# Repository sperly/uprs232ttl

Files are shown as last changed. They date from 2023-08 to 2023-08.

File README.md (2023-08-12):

# uprs232ttl
TTL Serial Adapter for C64/C128 UserPort.

The adapter is based on a non-inverting cmos buffer chip, CD4050. Following signals are used from the C64/C128:
```
FLAG <- RX (via a jumper)
PB0  <- RX
PB1  -> RTS
PB6  <- CTS
PA2  -> TX
```

There are also jumpers to switch signal path to enable null-modem communication. The default position is marked on pcb and it set for null-modem communication.
```
J4:

 RX/TX
| o o |         Null-Modem
| o o |
  o o

 RX/TX
  o o           Controller-Peripheral
| o o |
| o o |

J5:

CTS/RTS
| o o |         Null-Modem
| o o |
  o o

CTS/RTS
  o o           Controller-Peripheral
| o o |
| o o |

```

The serial output is pin compatible with common serial-usb adapters:
```
1 - GND
2 - CTS
3 - VCC
4 - TX
5 - RX
6 - DTR

```

Jumper 1 is used for enabeling RX interupt on the C64/C128. And jumper 2 is enabeling power thru the serial adapter.
```
J1:

RX Int
| o |         RX interupt enabled
| o |

RX Int
  o           RX interupt disabled
  o 

J2:

 Pwr
| o |         Power feed from C64/C128 enabled
| o |

 Pwr
  o           Power feed from C64/C128 disabled
  o 

```

Top side of pcb:
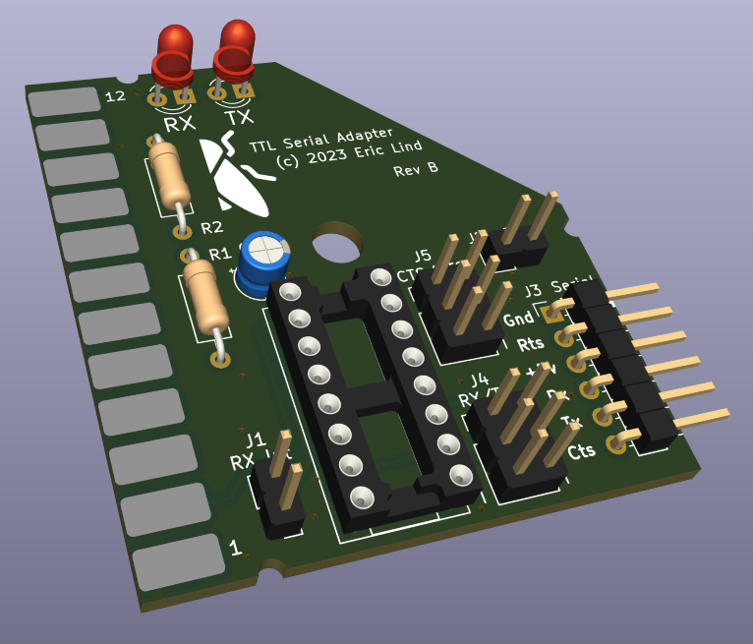
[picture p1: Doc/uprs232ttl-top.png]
Top view of pcb


Bottom side of pcb, also containing info on jumper settings:
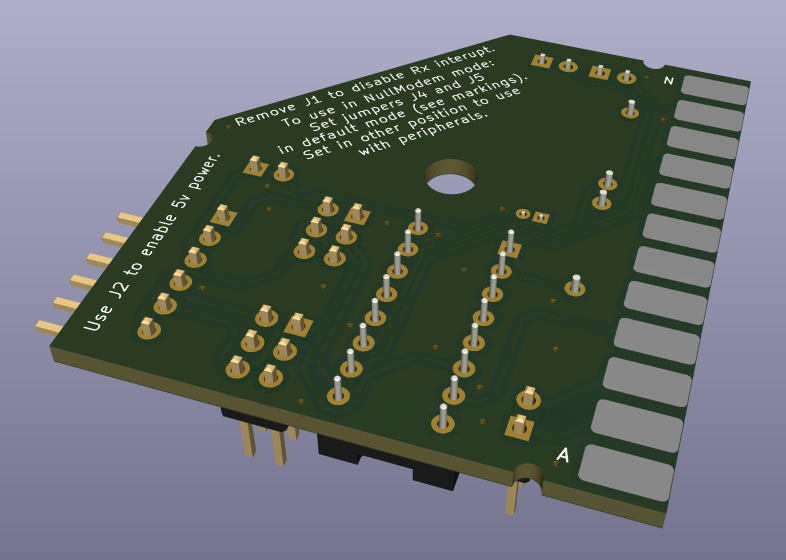
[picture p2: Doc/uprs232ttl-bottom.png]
Bottom view of pcb


Case with pcb:
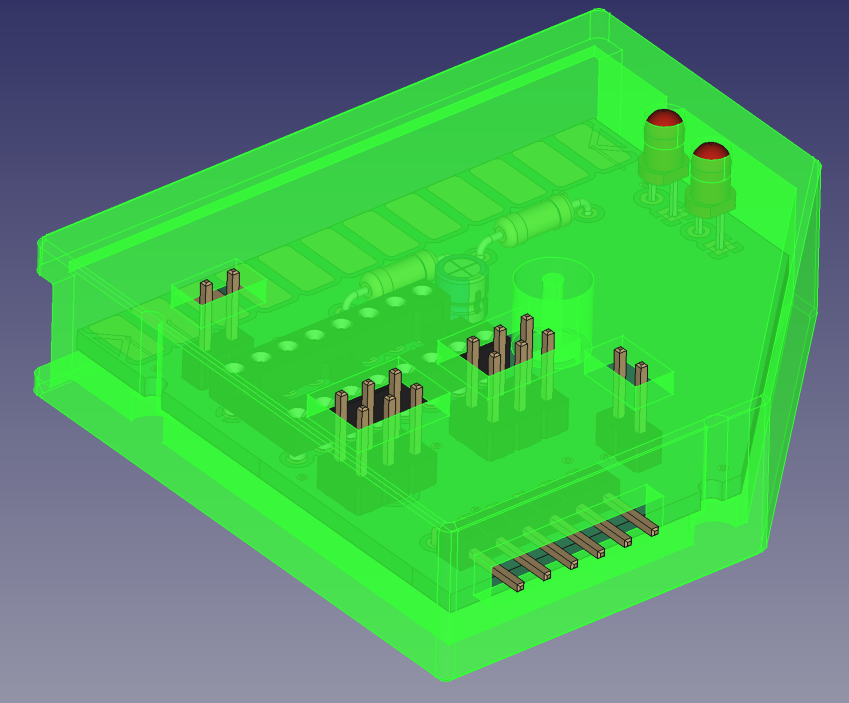
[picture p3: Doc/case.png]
Case with pcb


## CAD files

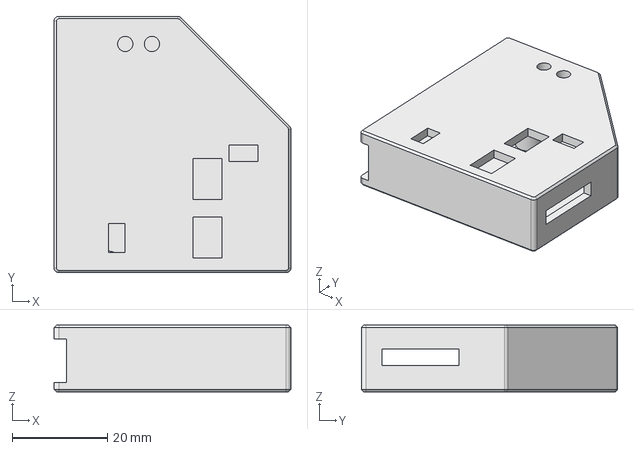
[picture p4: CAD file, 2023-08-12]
Case/uprs232ttl.FCStd
49.7 x 53.8 x 14.0 mm

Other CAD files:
Case/uprs232ttl.stl

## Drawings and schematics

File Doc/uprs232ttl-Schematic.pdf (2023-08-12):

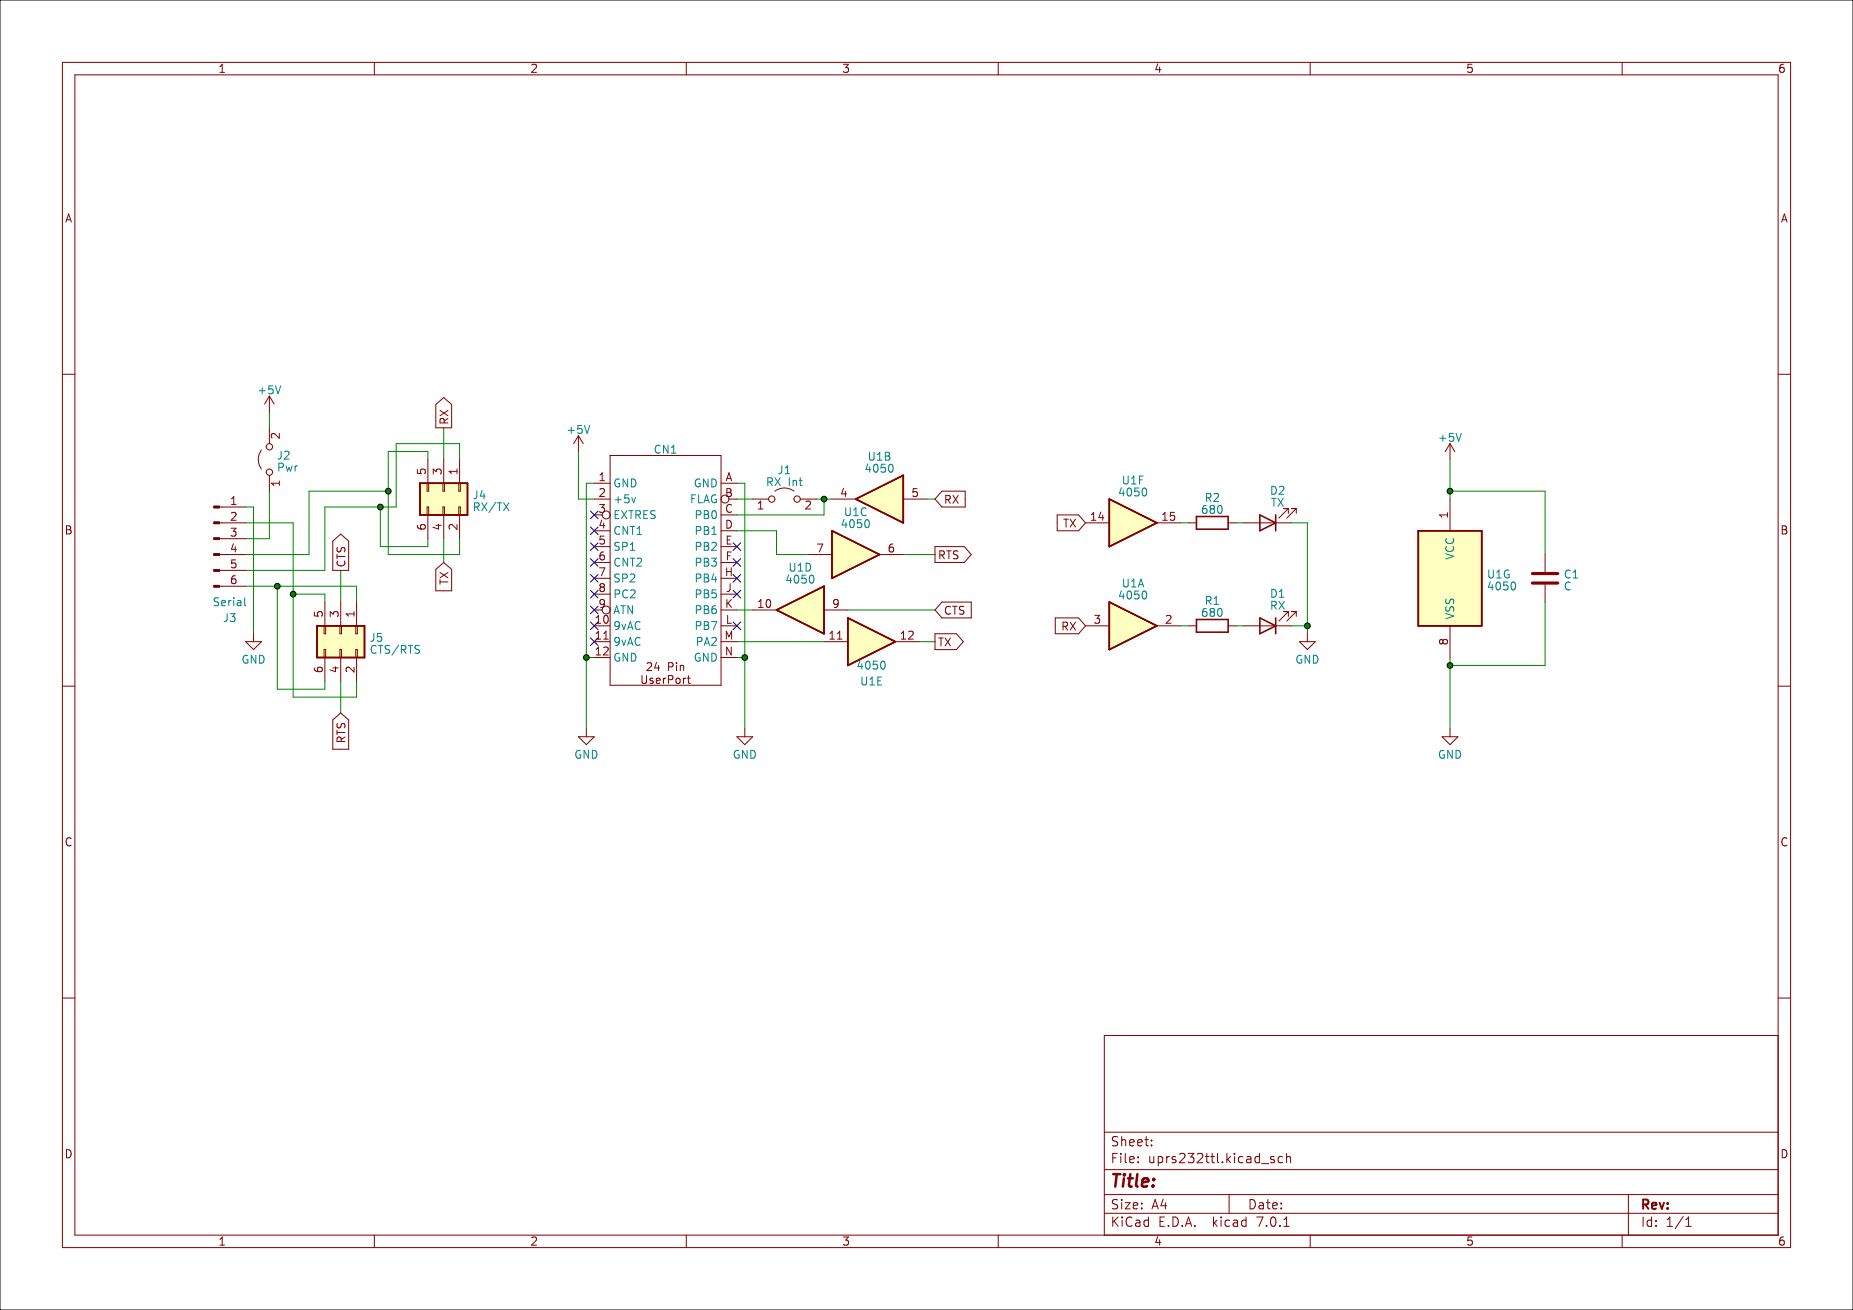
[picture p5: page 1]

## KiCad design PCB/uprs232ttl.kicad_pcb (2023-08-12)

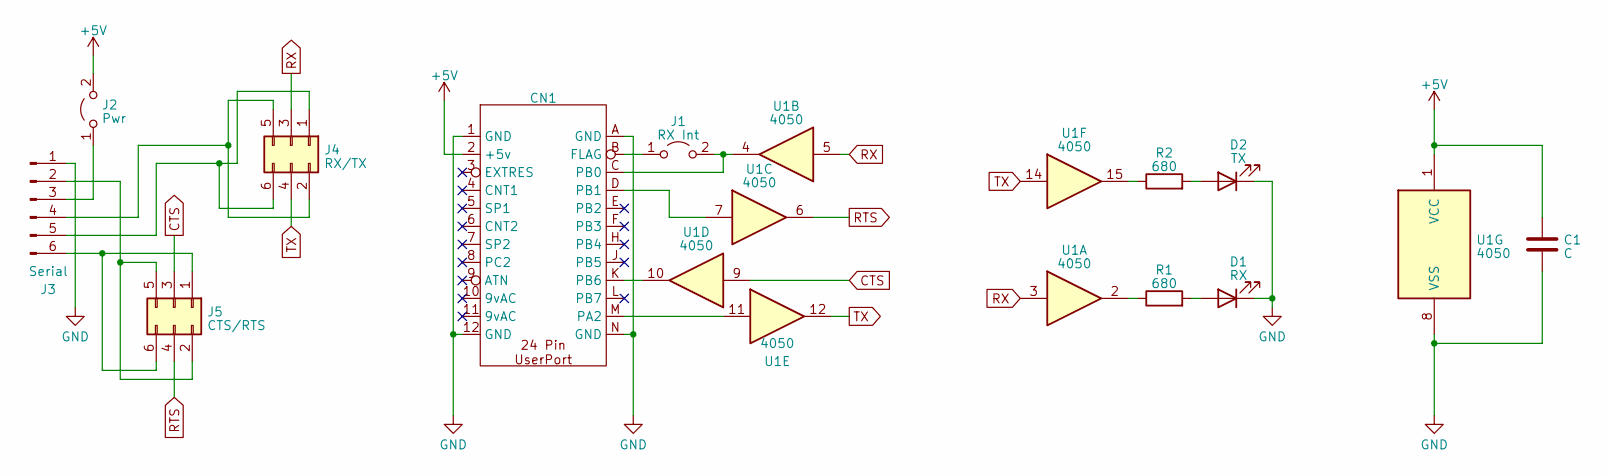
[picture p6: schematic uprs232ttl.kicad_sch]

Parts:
C1: C; CP_Radial_D4.0mm_P1.50mm
CN1: userport_cbm
D1: RX; LED_D3.0mm
D2: TX; LED_D3.0mm
J1: RX Int; PinHeader_1x02_P2.54mm_Vertical
J2: Pwr; PinHeader_1x02_P2.54mm_Vertical
J3: Serial; PinHeader_1x06_P2.54mm_Horizontal
J4: RX/TX; PinHeader_2x03_P2.54mm_Vertical
J5: CTS/RTS; PinHeader_2x03_P2.54mm_Vertical
R1, R2: 680; R_Axial_DIN0207_L6.3mm_D2.5mm_P10.16mm_Horizontal
U1: 4050; DIP-16_W7.62mm_Socket

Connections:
+5V: C1.1, CN1.2 (+5v), J2.2 (B), U1.1 (VCC)
CTS: J5.3, U1.9
GND: C1.2, CN1.1 (GND), CN1.12 (GND), CN1.A (GND), CN1.N (GND), D1.1 (K), D2.1 (K), J3.1, U1.8 (VSS)
unnamed: CN1.B (FLAG), J1.1 (A)
unnamed: CN1.M (PA2), U1.11
unnamed: CN1.C (PB0), J1.2 (B), U1.4
unnamed: CN1.D (PB1), U1.7
unnamed: CN1.K (PB6), U1.10
unnamed: D1.2 (A), R1.2
unnamed: D2.2 (A), R2.2
unnamed: J2.1 (A), J3.3
unnamed: J3.2, J5.2, J5.5
unnamed: J3.4, J4.2, J4.5
unnamed: J3.5, J4.1, J4.6
unnamed: J3.6, J5.1, J5.6
unnamed: R1.1, U1.2
unnamed: R2.1, U1.15
RTS: J5.4, U1.6
RX: J4.3, U1.3, U1.5
TX: J4.4, U1.12, U1.14

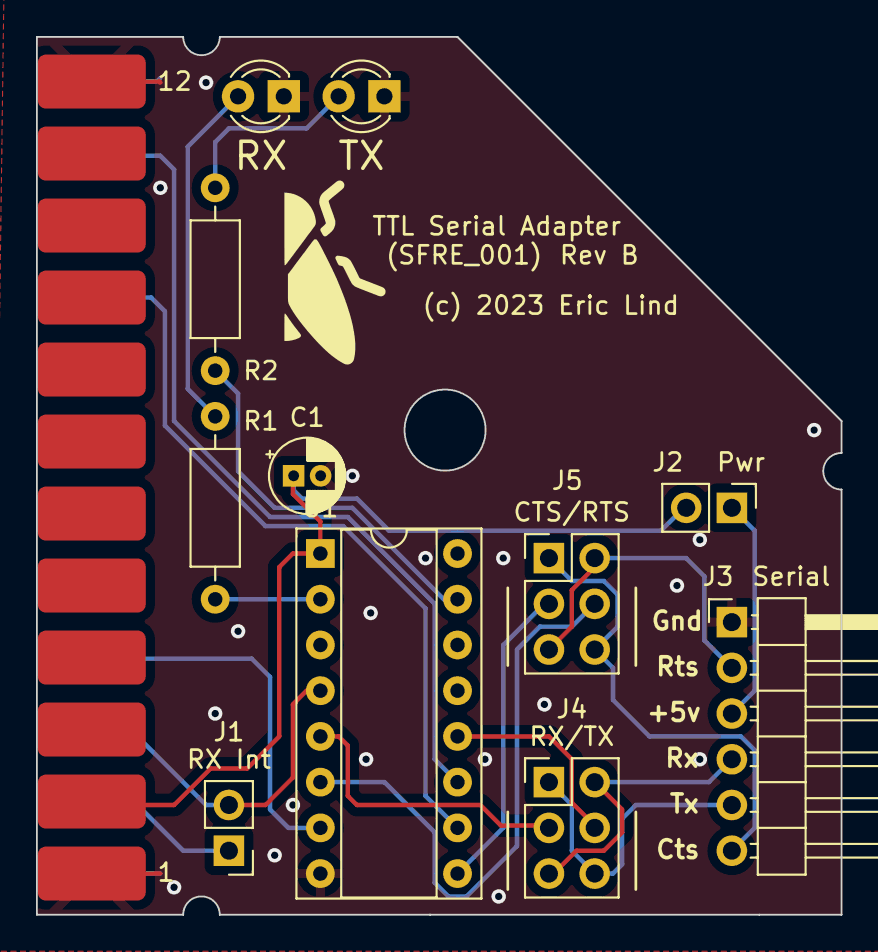
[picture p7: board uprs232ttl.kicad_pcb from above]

Board: 2 copper layers, 44.7 x 48.8 mm, 12 parts (0 on the bottom side), 20 nets.

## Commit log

2023-08-12 Added case, pcb and userport component
    [uprs232ttl-B_Cu.gbr, uprs232ttl-B_Mask.gbr, uprs232ttl-B_Paste.gbr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]
2023-08-12 Added a bottom view of pcb.
2023-08-12 Added a case image and more description in README
2023-08-12 Create .gitignore for pcb folder
2023-08-12 Updated board name
    [uprs232ttl-B_Cu.gbr, uprs232ttl-B_Mask.gbr, uprs232ttl-B_Paste.gbr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]

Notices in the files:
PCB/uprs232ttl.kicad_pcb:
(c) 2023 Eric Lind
